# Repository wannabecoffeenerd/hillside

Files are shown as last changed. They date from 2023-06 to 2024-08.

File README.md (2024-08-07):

# Hillside View Ergonomic Keyboard

3x6                       |  3x5
:-------------------------:|:-------------------------:
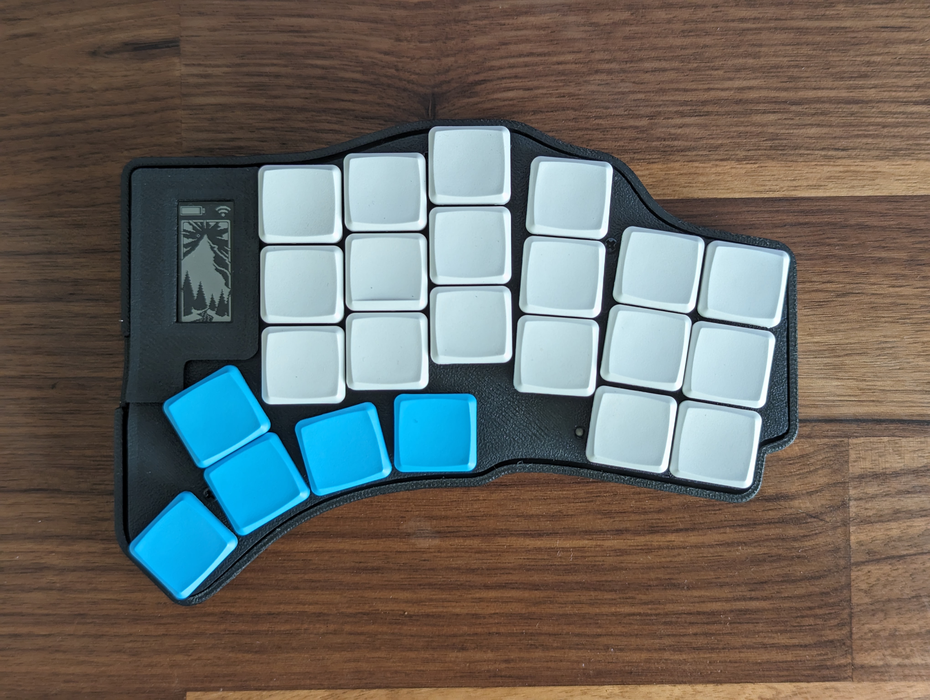
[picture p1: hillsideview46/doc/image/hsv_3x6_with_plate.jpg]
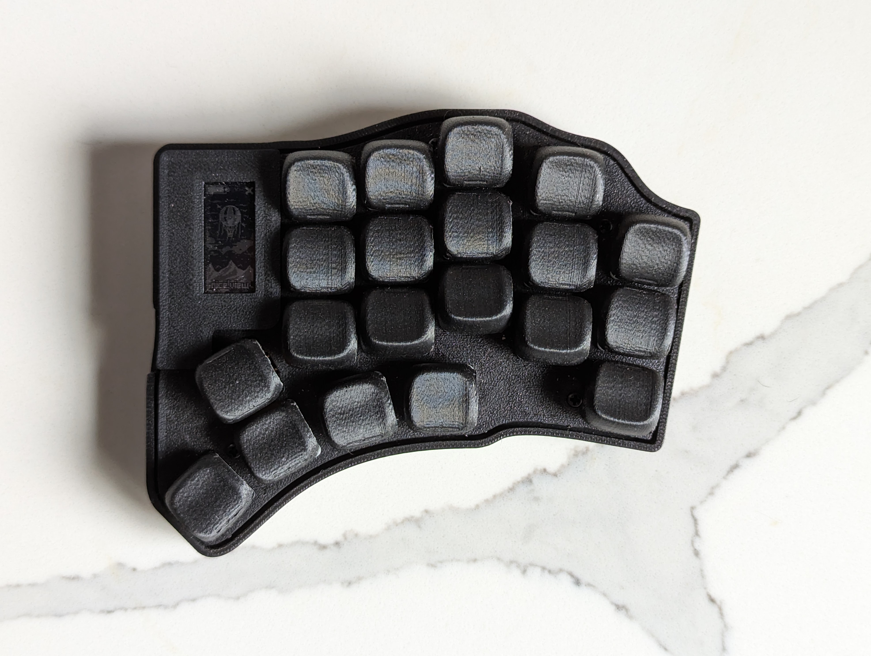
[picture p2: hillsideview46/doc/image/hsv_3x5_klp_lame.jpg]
  |  

The HillSideView (HSV) is a modified version of the [Hillside 46](https://github.com/mmccoyd/hillside). It is a 
 wireless (or wired) [40%](https://deskthority.net/wiki/40%25) 
 split-[ergonomic](https://deskthority.net/wiki/Ergonomic_keyboard) 
 keyboard with a 
 [column-stagger](https://deskthority.net/wiki/Staggering#Columnar_layout) 3x6+5 or a 3x5+5 layout.

The main features that the HSV adds over the Hillside 46 are:
- [nice!view](https://github.com/getkeops/keops/tree/main) e-paper display for better battery life
- Cleaner outer pinky column cut-off
- Support for a cirque trackpad with an FFC connector on the PCB itself
- Case design with support for large 750-3000 mAh batteries under the PCB
- Magnetic tenting stand with the case
- Under PCB mount for the MCU for a cleaner top display mounting

The HSV has optional factory parts soldering (PCBA) except for the switches, MCU, display, TRRS, LEDs, battery switch, and optional hotswap sockets.

Other features of the HSV are:

- Choc-spaced keys, aggressive stagger, five thumb keys
- Break-off outer pinkie column
- Tenting puck support
- QMK and wireless ZMK firmware
- Nice!nano battery power switch
- Encoder support
- Underglow from four or five SK6812-MINI-Es
- Reversible PCB
- Detailed BOM and default keyboard rationale.
- SMT diodes, resistors, capacitors, and reset switch

*Keycaps*: HillSideView is _only_ suitable for choc v1 switches and keycaps based on an 18 x 17mm switch spacing, such as the [MBK](https://mkultra.click/mbk-choc-keycaps), [Lowprokb LDSA](https://lowprokb.ca/products/ldsa-low-profile-blank-keycaps) or [KLP Lamé](https://github.com/braindefender/KLP-Lame-Keycaps/). Not MX ones, nor 18 x 18mm ones such as Work Louder, nor Kailh Choc Transparent.

## Keymap

HillSideView includes ZMK Firmware
- [full size](https://github.com/mike1808/zmk-config)
- [five column](https://github.com/wannabecoffeenerd/zmk-config)

QMK firmware can be adapted from the [Hillside firmware](https://github.com/qmk/qmk_firmware/tree/master/keyboards/handwired/hillside) 

The default keymap for the five column build:


## Key Use

I expect most people will primarily use either the tucked three thumbs or the extended three (not counting the upper thumb). They can choose where the thumb arc suits them best. I find the thumb finger is best for reaching the upper thumb key; clearing the lower thumb requires some care, but it is still very useful. The middle finger also handily reaches the most tucked thumb key, as the open space is a good reference. The keys outside of the primary three thumb keys are convenient for infrequent lock layers, escape, or for use when not actively typing for things such as mute.

## Why

The main reason for this project is to make the keyboard more wireless friendly by adding the e-paper display and allowing experimenting with using a cirque trackpad (once ZMK support for it is more stable)

## Hardware and Build Guide

See the [original Hillside wiki](https://github.com/mmccoyd/hillside/wiki)
 first for PCB ordering, parts links and a build guide with pictures.

See the [HSV wiki](https://github.com/wannabecoffeenerd/HillSideView/wiki) for HSV specific
 build guide.

 ### Bill of Materials (BOM)

| **Component** | **Quantity per keeb** | **URL** | **Source** | **Price Per SKU** |
|---|---|---|---|---|
| PCB | 1 | JLCPCB | JLCPCB | 10.778 |
| nice!nano | 2 | https://typeractive.xyz/products/nice-nano | typeractive.xyz | 25 |
| nice!view | 2 | https://typeractive.xyz/products/nice-view | typeractive.xyz | 20 |
| switches - pro pink or other (10 pack) | 5 | https://lowprokb.ca/collections/keyboards/products/kailh-choc-low-profile-switches | lowprokb.ca | 5 |
| mill-max sockets | 100 | https://www.mouser.com/ProductDetail/Mill-Max/0305-2-15-80-47-80-10-0?qs=QtQX4uD3c2Uys0ai6Tr8NQ%3D%3D | mouser.com | 0.1 |
| keycaps (10 pack) | 5 | https://typeractive.xyz/products/mbk-keycaps | typeractive.xyz | 3.5 |
| 2x battery - 750 mAh | 2 | https://typeractive.xyz/products/lithium-battery-750mah | typeractive.xyz | 6 |
| MCU sockets - low clearance | 2 | https://www.mouser.com/ProductDetail/Mill-Max/310-47-132-41-001000?qs=5aG0NVq1C4z8UdNlP%252Bvotg%3D%3D  | mouser.com | 2.17 |
| Standoffs | 8 | https://www.mouser.com/ProductDetail/Wurth-Elektronik/970060244?qs=%252BEew9%252B0nqrCEb5Os0atlaA%3D%3D | mouser.com | 0.43 |
| MCU pins | 64 | https://www.mouser.com/ProductDetail/Mill-Max/3320-0-00-15-00-00-03-0?qs=s8Nb1z4Wn%2FQ16WBIwCPrTw%3D%3D | mouser.com | 0.05 |
| power switches | 2 | https://www.mouser.com/ProductDetail/CK/JS202011AQN?qs=LgMIjt8LuD%252Bmsz6wAeWWtQ%3D%3D | mouser.com | 0.471 |

Some other optional parts:

| **Component** | **Quantity per keeb** | **URL** | **Source** | **Price Per SKU** |
|---|---|---|---|---|
| battery - 110 mAh | 2 | https://www.aliexpress.us/item/2255800150229489.html | aliexpress.us | 1.36 |
| battery - 2000 mAh | 2 | https://www.aliexpress.us/item/3256803882039204.html | aliexpress.us | 5.18 |
| EC11 rotary encoders | 0.4 | https://www.aliexpress.us/item/2251832789732148.html | aliexpress.us | 5.08 |
| aluminum knob for EC11 | 1 | https://www.aliexpress.us/item/3256801125707035.html | aliexpress.us | 6.85 |

 ### 3DP case

 The HSV is designed to be used with a 3D printed case. STLs for the case are [here](https://github.com/wannabecoffeenerd/HillSideView/tree/main/hillsideview46/case)

 To main design principles for the case are:
 - Ability to use a large battery mounted under the PCB and
 - Keep the top of the HSV fairly low profile for portability and ensure nothing sticks up above the keys.

 This is achieved by having an empty cavity under the PCB that allows using up to a 2000 mAh 306070 battery. This also allows for mounting the MCU on the underside of the PCB and having the nice!view display sit fairly low on top of the PCB.
 
 The case supports tenting using a magnetic tenting stand that uses 10x1 magnets in the case and 10x3 magnets in the stand. This also allows the two sides to attach magnetically for travel.

 

## Acknowledgments

Several keyboards have influenced this boards, primarily the
  [Hillside 46](https://github.com/mmccoyd/hillside), but also
  [Atreus](https://shop.keyboard.io/products/keyboardio-atreus),
  [Lily58](https://github.com/kata0510/Lily58),
  [Kyria](https://splitkb.com/collections/keyboard-kits/products/kyria-pcb-kit),
  [Corne](https://github.com/foostan/crkbd) and
  [Ferris](https://github.com/pierrechevalier83/ferris).

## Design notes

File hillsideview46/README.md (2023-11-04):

# Hillside 46 Ergonomic Keyboard

Hillside46 keyboard

Hillside 46 is a split ergonomic keyboard with 3x6+5 choc-spaced keys.
It has the aggressive stagger of the Ferris plus
  finger splay,
  a longer thumb arc and break-off outer pinkie columns.

Splaying the columns lets our fingers more naturally follows our hand mechanics.
See the Hillside [family readme](../README.md) for features common to all hillside boards. Specific to the Hillside 46 are: 

* Optional factory parts soldering except for the switches, MCU, TRRS, LEDs and battery switch.
* Fab with PCBA is $9 per keyboard for five keyboards, plus shipping.  
  Or $12 each for two keyboards, if the diodes etc are on the left's top side and the right's bottom side.
* Encoder: Two spots for one per side at either: upper or tucked thumb
* Reversible 100 x 143mm PCB
* Optional hotswap with Mill-Max switch sockets (not part of PCBA)

Hillside includes:
 [QMK firmware](https://github.com/qmk/qmk_firmware/tree/master/keyboards/handwired/hillside) 
 with .json, .c, 
 [via](https://github.com/mmccoyd/hillside/wiki/hill_46/via_config.json) and 
 [vial](https://github.com/mmccoyd/vial-qmk/tree/hillside_46/keyboards/handwired/hillside/46/keymaps) keymaps,
 [ZMK Firmware](https://github.com/mmccoyd/zmk-config),
 a [keyboard layout editor](http://www.keyboard-layout-editor.com/) 
 loadable [diagram](https://github.com/mmccoyd/hillside/wiki/hill_46/keyboard-layout-editor.json)
 and a [draw.io](https://app.diagrams.net) 
 loadable [diagram](https://github.com/mmccoyd/hillside/wiki/hill_46/drawio_keymap.png).

## Keymap

The default keymap has a navigation and editing layer and alternate hand modifiers for all keys. See the [keymap descrition](https://github.com/mmccoyd/hillside/wiki/Hillside%2046%20Keymap) for details.

Hillside46 keyboard (https://github.com/mmccoyd/hillside/wiki/Hillside%2046%20Keymap)

## Hardware and Build Guide

See [Ordering Hillside 46](https://github.com/mmccoyd/hillside/wiki/Ordering%20Hillside%2046) 
  for how to order
 and the [wiki](https://github.com/mmccoyd/hillside/wiki)
  generally for parts links and a build guide with pictures.

# Why

The splay is there because your finger tips do not move parallel to each other when you curl and extend them. It makes sense for your keyboard columns to match that.

## Layout Tester
To test if the key layout suits your fingers,
 print these in landscape mode. 
 
  - Click on each to open the GitHub file view in a new tab. 
  - Click on raw to see just the file in the browser tab.
  - Tell your browser to print the file. But ensure it is at 100% and in landscape mode.
  
SVG files contain dimension information, so your browser should print it the correct size regardless of what size paper you are using.
As an extra check, the images each contain marked length lines, which you can check with a ruler.

The images are black lines on whatever the background is, so they do not like browser dark mode backgrounds, but will print black on white.

| switches Switch Layout Left | switches Switch Layout Right |
|---|---|

## Images

<div style="background-color:#DCDCDC;">

Schematic
</div> 

Hillside46 keyboard

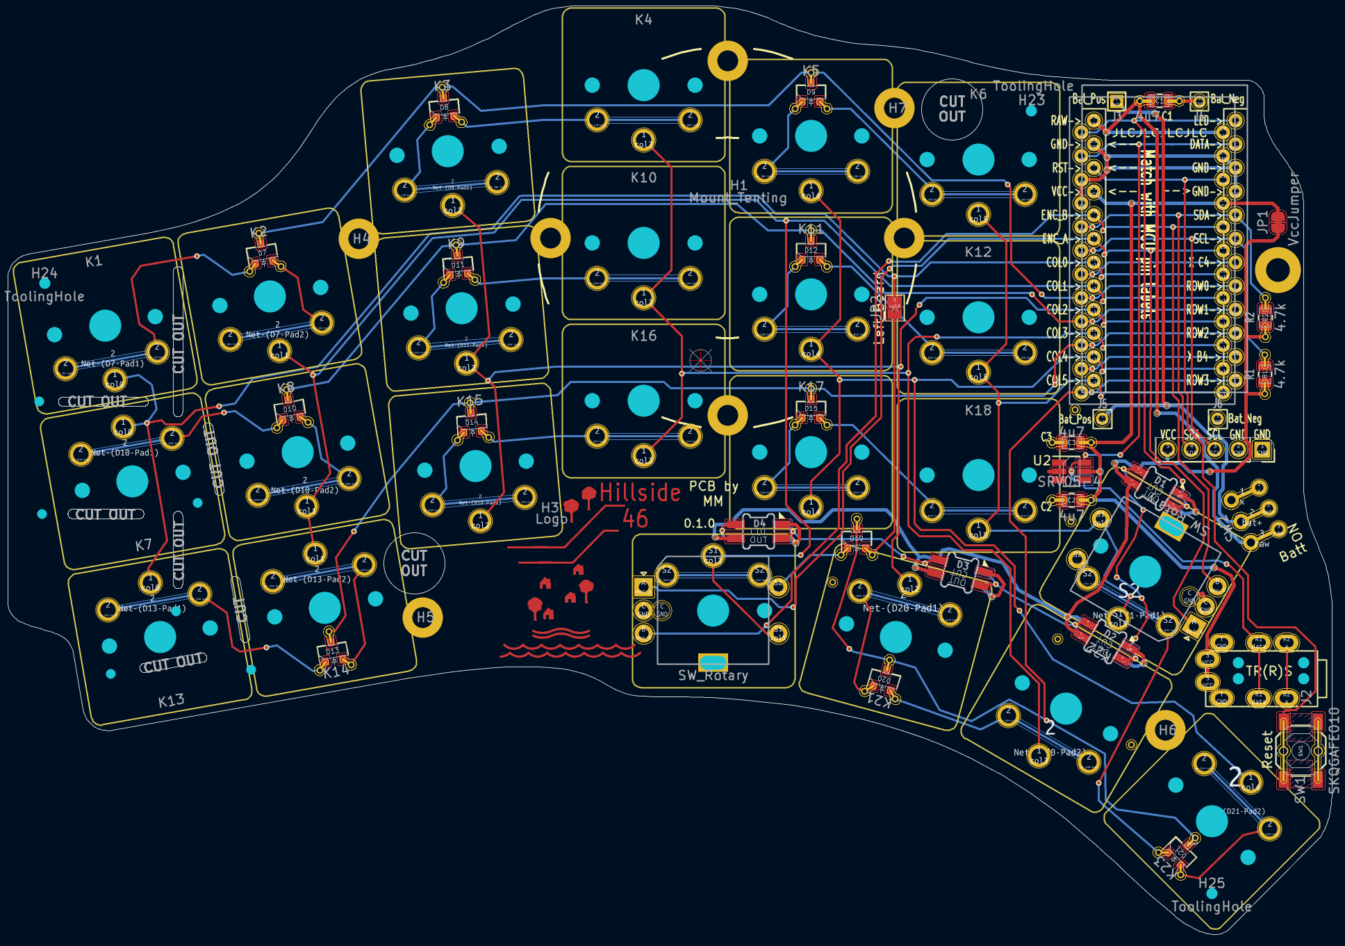
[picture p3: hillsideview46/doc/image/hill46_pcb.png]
pcb PCB


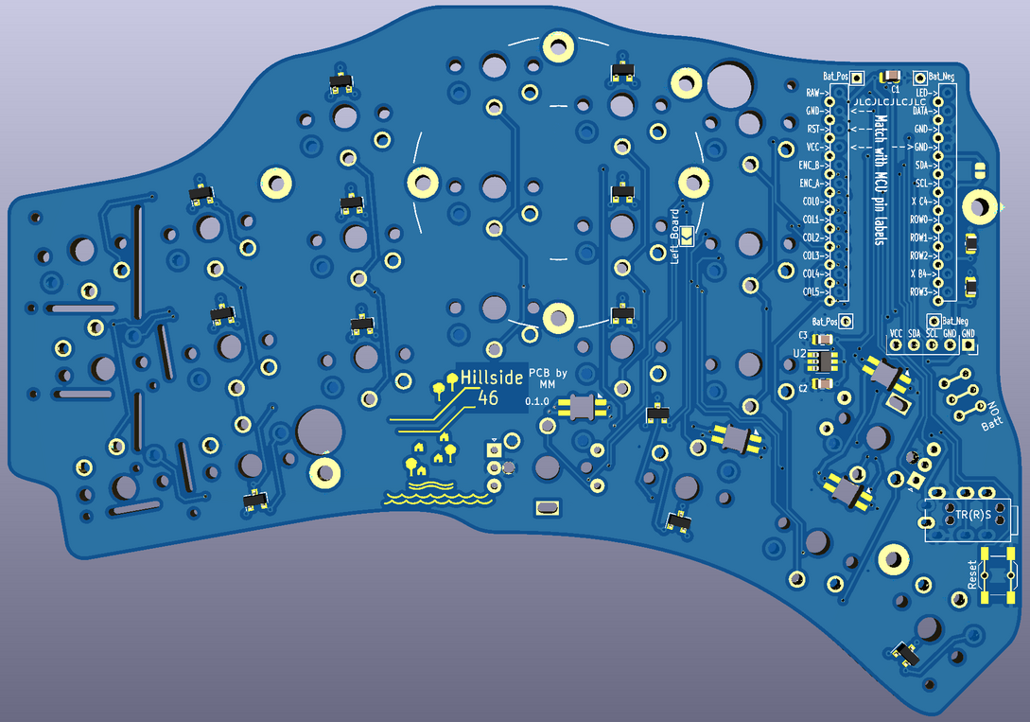
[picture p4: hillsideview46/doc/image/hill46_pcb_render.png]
render Front Render


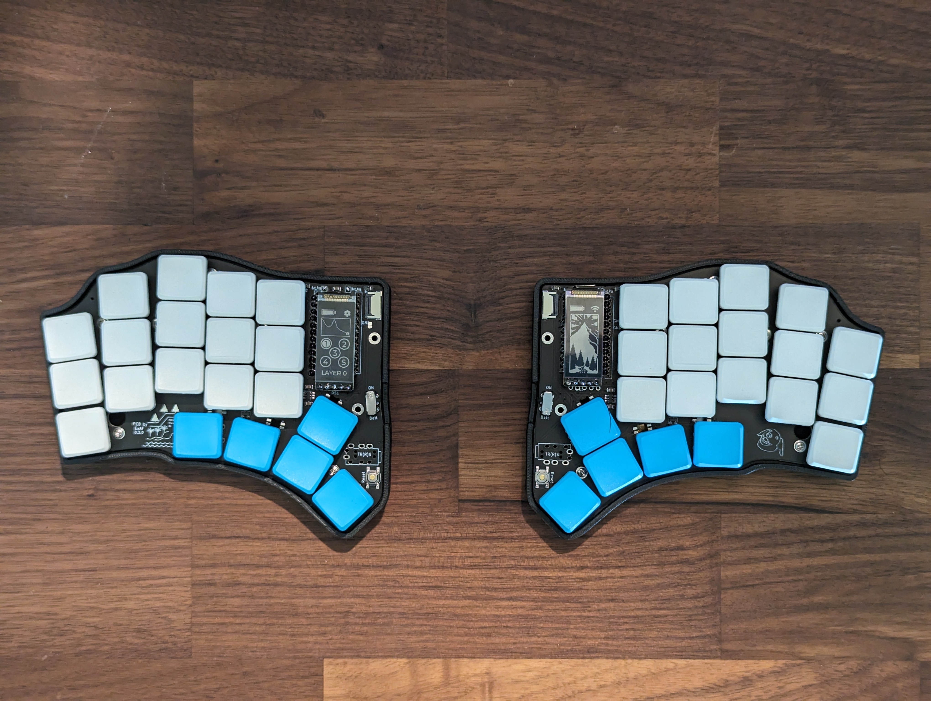
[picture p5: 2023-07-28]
hillsideview46/doc/image/hsv_3x5.jpg

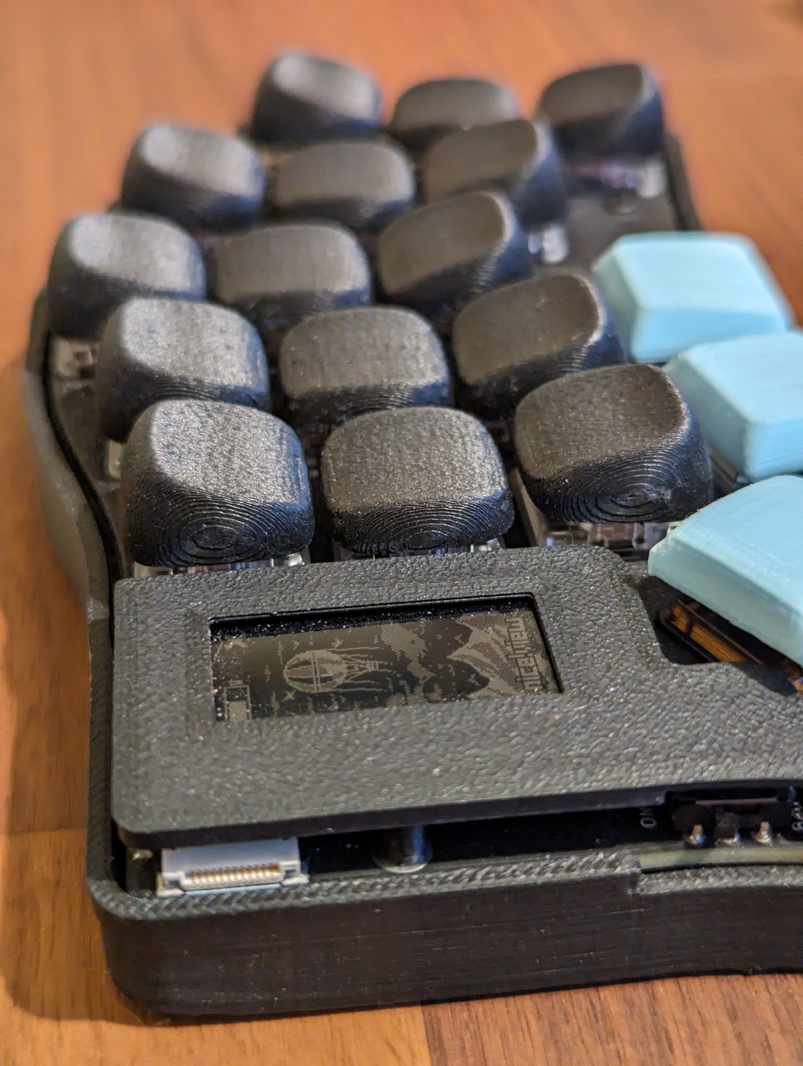
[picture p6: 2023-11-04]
hillsideview46/doc/image/hsv_klp_lame.jpg

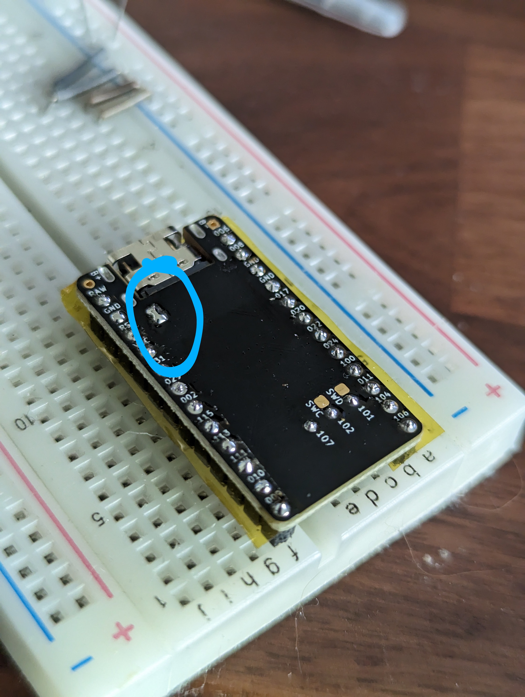
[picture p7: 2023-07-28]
hillsideview46/doc/image/nice_nano_fast_charging.jpg

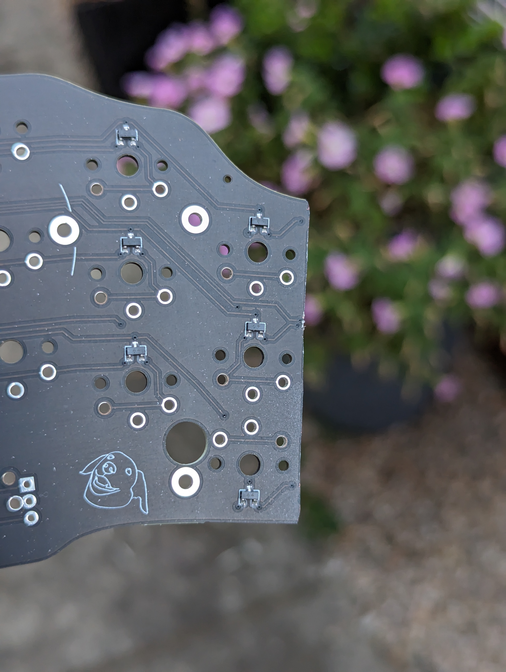
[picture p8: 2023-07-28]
hillsideview46/doc/image/hsv_3x5_pcb.jpg

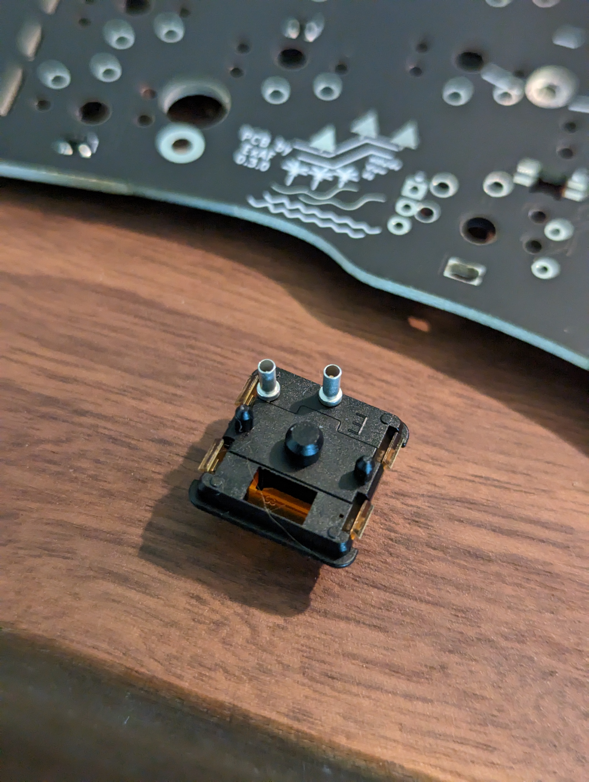
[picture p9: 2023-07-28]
hillsideview46/doc/image/hotswap_on_switch.jpg

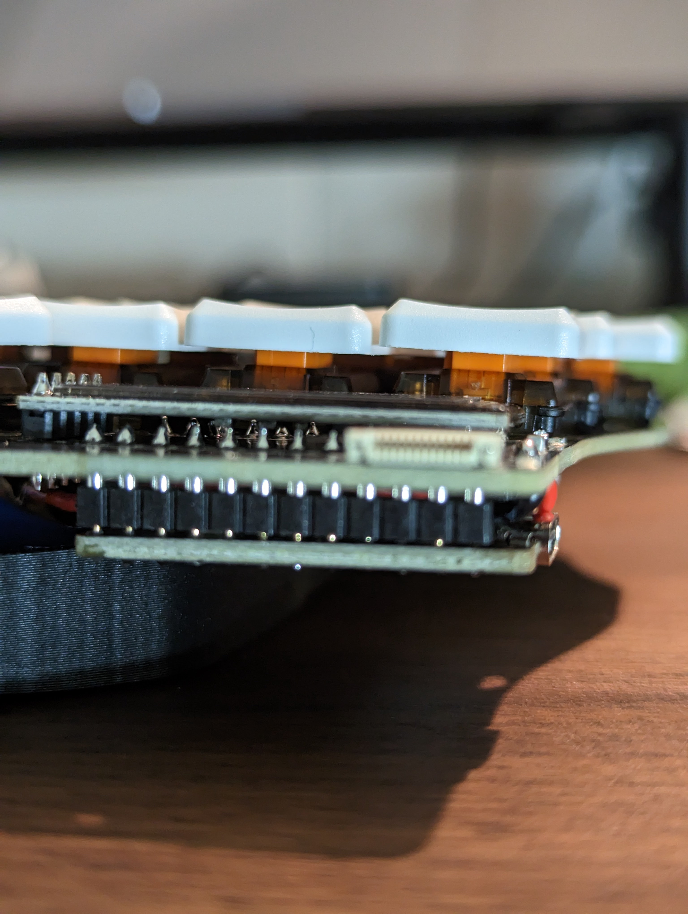
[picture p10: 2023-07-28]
hillsideview46/doc/image/hsv_display_pcb_mcu_side_view.jpg

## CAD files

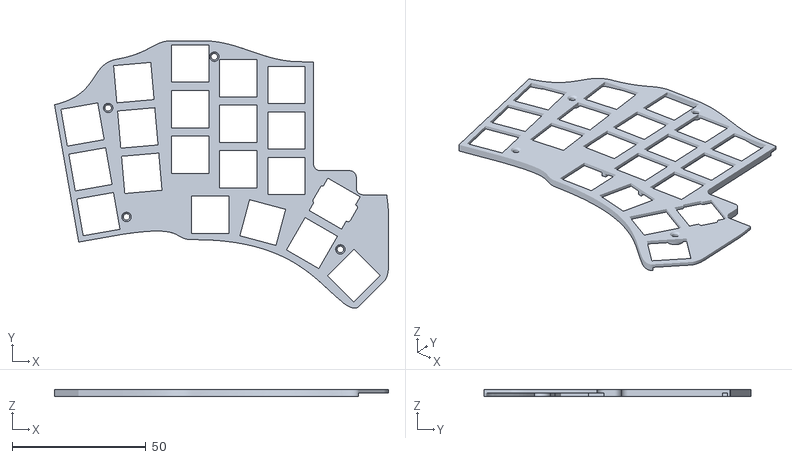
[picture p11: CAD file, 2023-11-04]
hillsideview46/case/5_column/no_pinky_switch_plate.stl
124.8 x 99.9 x 2.50

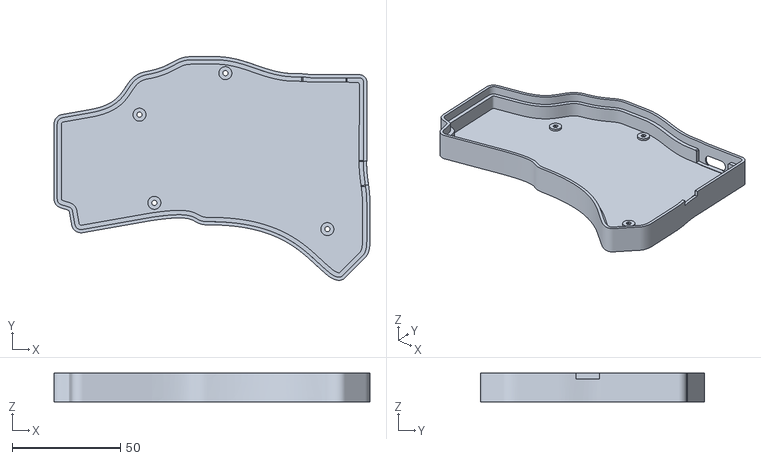
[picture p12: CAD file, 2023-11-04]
hillsideview46/case/6_column/bottom+wall.stl
145.9 x 103.3 x 13.2

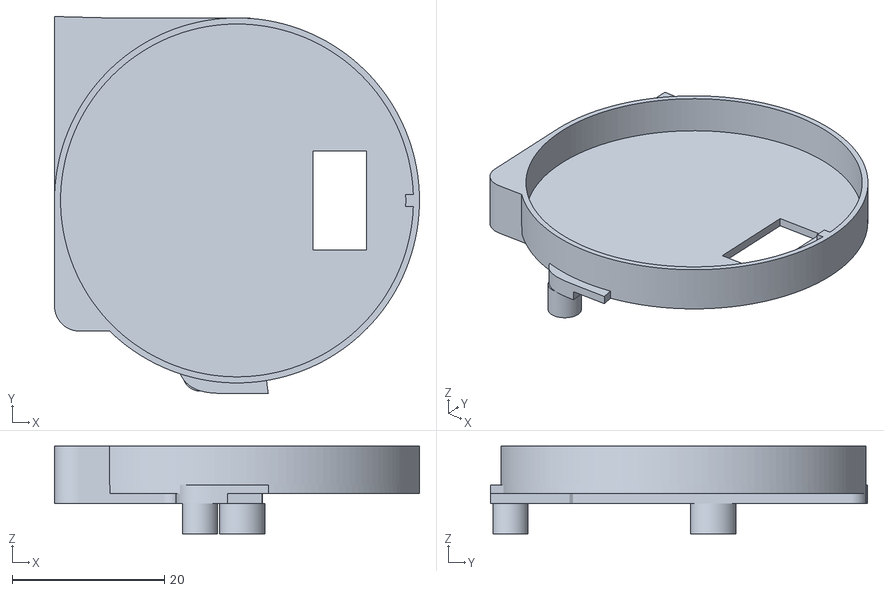
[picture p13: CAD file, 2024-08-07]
hillsideview46/case/cirque/cirque_trackpad_holder.stl
48.0 x 49.6 x 11.6

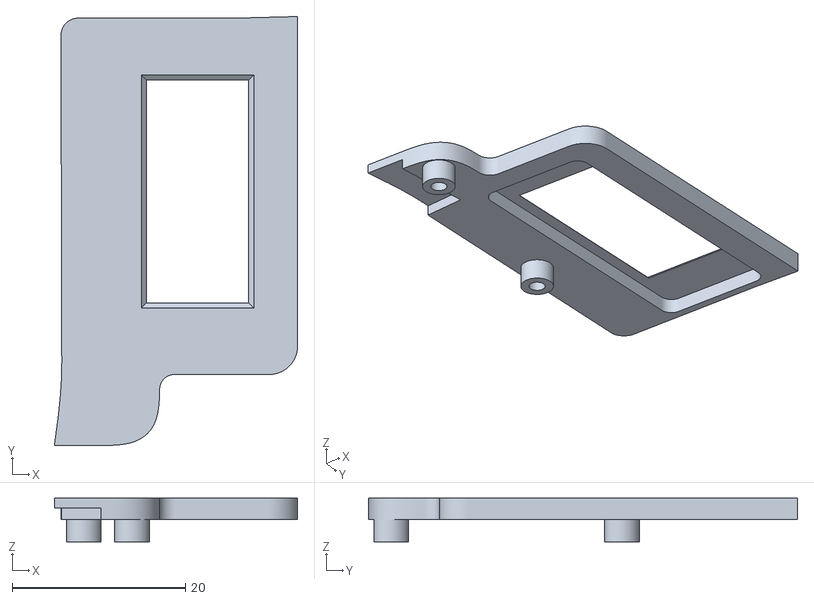
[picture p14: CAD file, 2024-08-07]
hillsideview46/case/display_cover/display_cover_right.stl
28.1 x 49.6 x 5.05

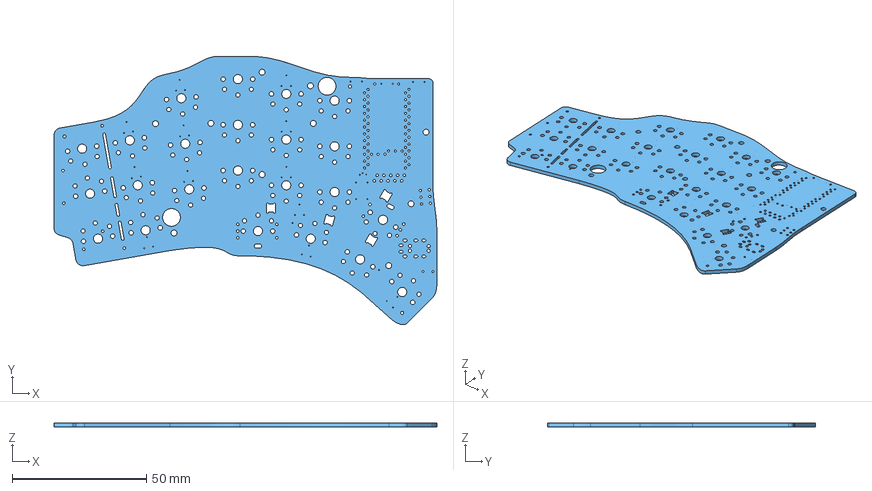
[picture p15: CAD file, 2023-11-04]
hillsideview46/hillsideview46.step
142.5 x 99.9 x 1.60 mm

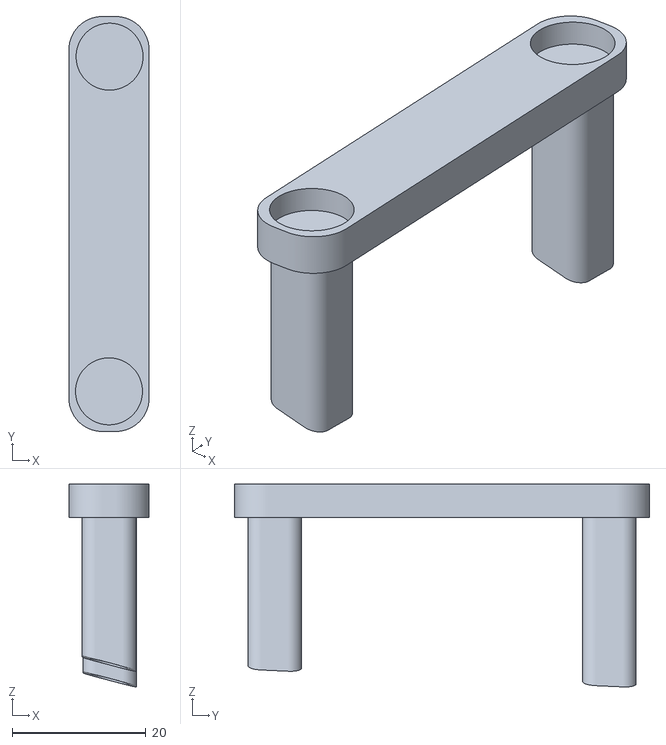
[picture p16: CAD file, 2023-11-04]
hillsideview46/case/5_column/no_pinky_tenting_stand.stl
12.0 x 62.0 x 30.3

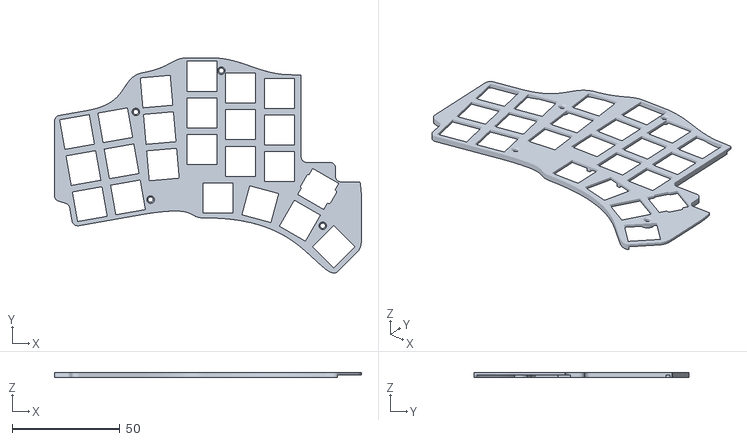
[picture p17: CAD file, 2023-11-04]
hillsideview46/case/6_column/switch_plate.stl
142.5 x 99.9 x 2.50

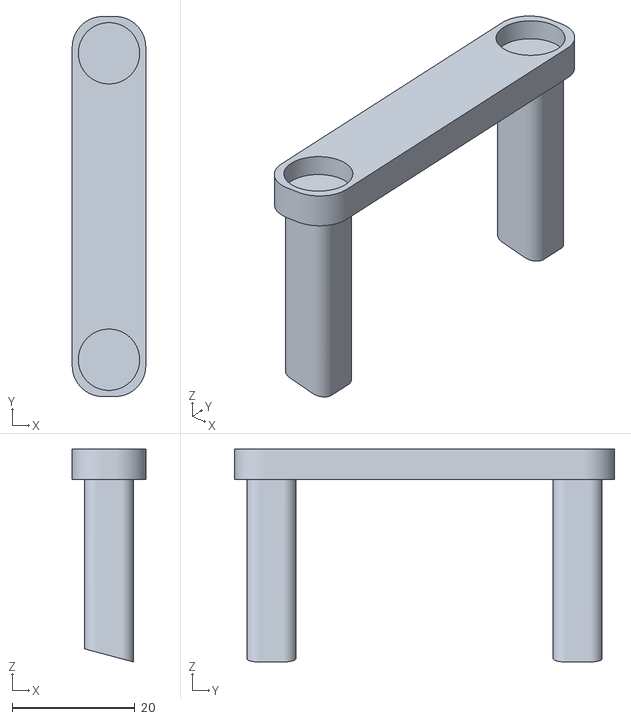
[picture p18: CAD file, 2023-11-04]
hillsideview46/case/6_column/tenting_stand.stl
12.0 x 62.0 x 34.7

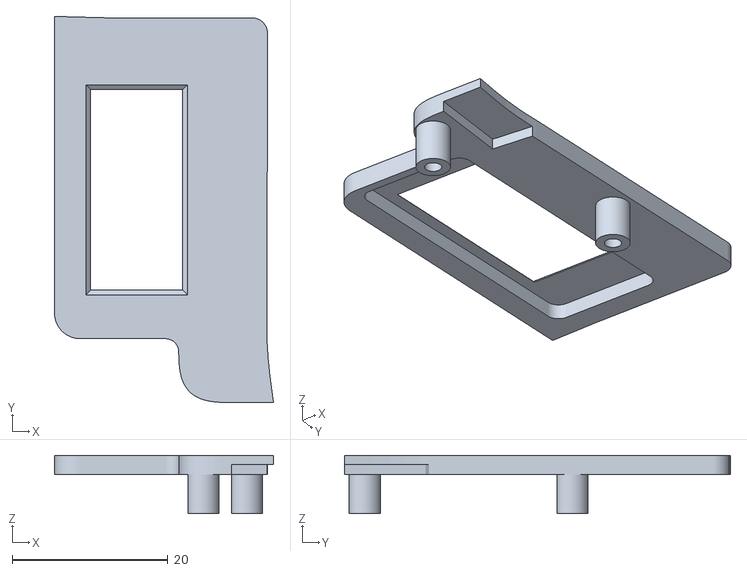
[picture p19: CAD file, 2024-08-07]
hillsideview46/case/display_cover/display_cover_millmax.stl
28.1 x 49.6 x 7.45

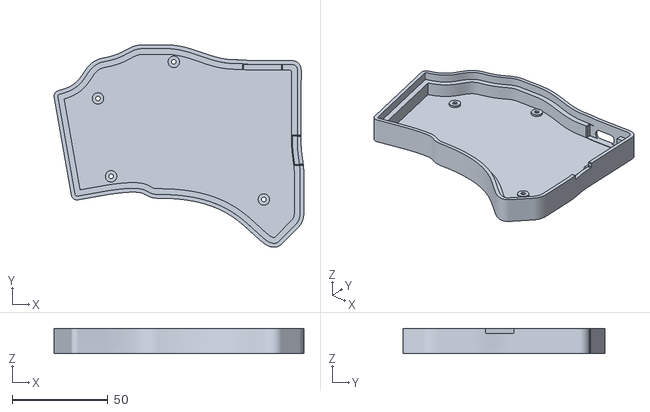
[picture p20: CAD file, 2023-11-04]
hillsideview46/case/5_column/no_pinky_bottom+wall.stl
130.7 x 105.9 x 13.2

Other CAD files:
hillsideview46/case/display_cover/display_cover.stl
hillsideview46/case/5_column/hillside46 - switch_plate.step
hillsideview46/case/display_cover/display_cover_right_millmax.stl
hillsideview46/case/5_column/no_pinky_switch_plate_minimal.stl

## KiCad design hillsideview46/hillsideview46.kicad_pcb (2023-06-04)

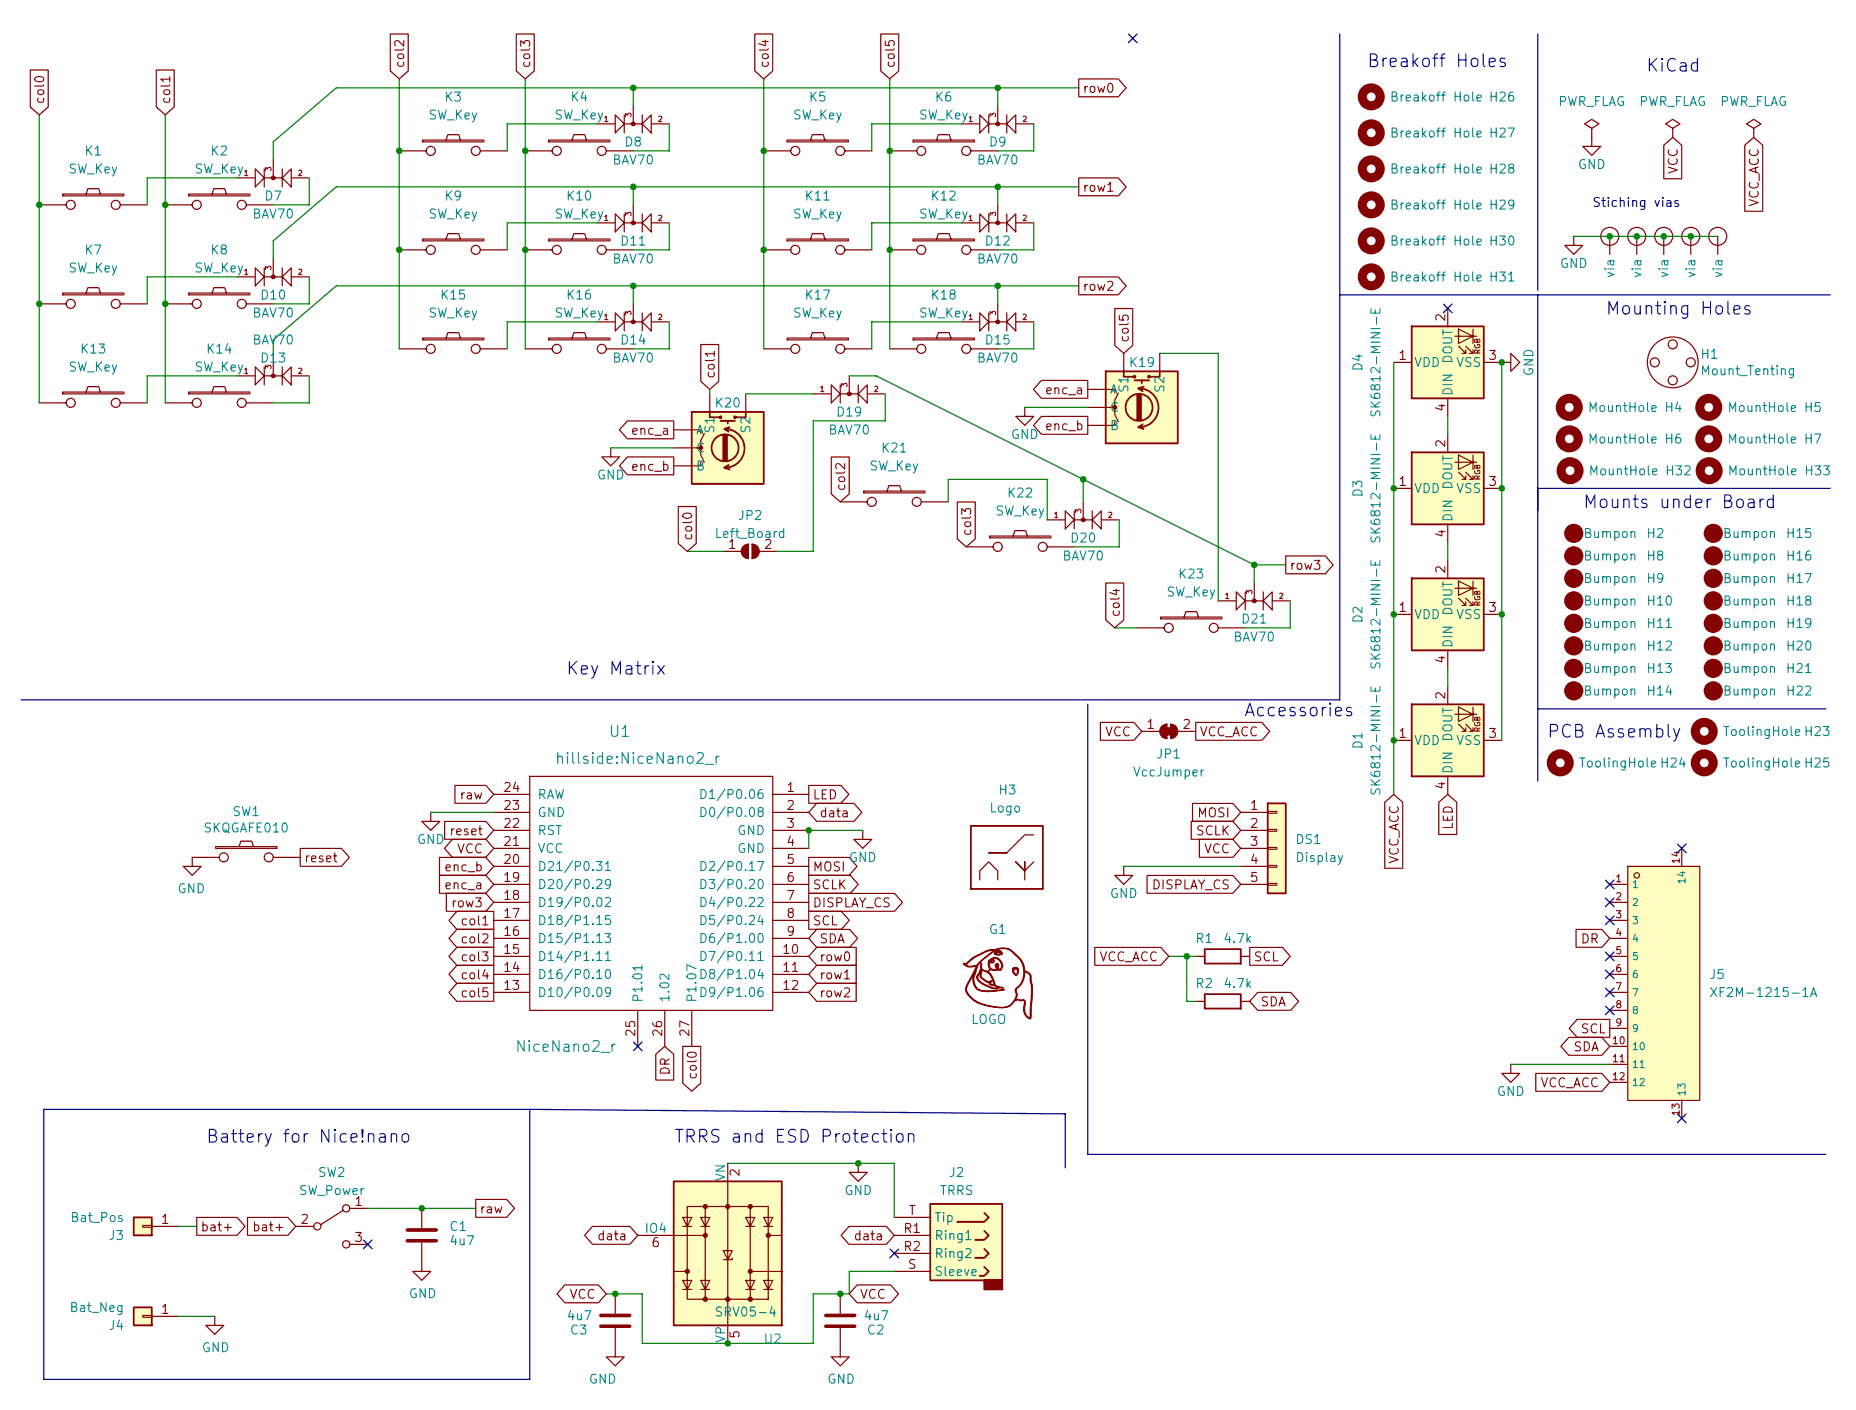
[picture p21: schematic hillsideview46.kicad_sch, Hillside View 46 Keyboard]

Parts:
C1, C2, C3: 4u7; C_0805_2012Metric; JLC Type Basic
D1, D2, D3, D4: SK6812-MINI-E
D7, D8, D9, D10, D11, D12, D13, D14, D15, D19, D20, D21: BAV70; SOT-23; LCSC C68978
DS1: Display; NiceView
G1: LOGO; wowee
H1: Mount_Tenting; Tenting_Puck
H2, H8, H9, H10, H11, H12, H13, H14, H15, H16, H17, H18, H19, H20, H21, H22: Bumpon
H3: Logo; Hillside_Logo
H4, H5, H6, H7, H32, H33: MountHole; MountingHole_2.2mm_with_PCB_insert_rings
H23, H24, H25: ToolingHole; ToolingHole_1.152mm
H26, H27, H28, H29, H30, H31: Breakoff Hole; HoleBreakoff_1mm
J2: TRRS; MJ-4PP-9
J3: Bat_Pos; 1pin_conn
J4: Bat_Neg; 1pin_conn
J5: XF2M-1215-1A; FPC-SMD_12P-P0.50_XF2M-1215-1A; PARTREV A; JLC Type Extended
JP1: VccJumper; SolderJumper-2_P1.3mm_Bridged_RoundedPad1.0x1.5mm
JP2: Left_Board; SolderJumper-2_P1.3mm_Open_TrianglePad1.0x1.5mm
K1, K2, K3, K4, K5, K6, K7, K8, K9, K10, K11, K12, K13, K14, K15, K16, K17, K18, K21, K22, K23: SW_Key; pg1350-R_hotswap
K19, K20: SW_Rotary; pg1350-DR_rotary_hotswap
R1, R2: 4.7k; R_0805_2012Metric; LCSC C17673
SW1: SKQGAFE010; SW_SPST_SKQG_WithStem; LCSC C318884
SW2: SW_Power; SW_SPDT_JS202011AQN; LCSC C221662
U1: NiceNano2_r
U2: SRV05-4; SOT-23-6_Handsoldering_threenumbered; JLC Type Basic
V1, V2, V3, V4, V5: Via; VIA-0.8mm

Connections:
DISPLAY_CS: DS1.5, U1.7 (D4/P0.22)
DR: J5.4, U1.26 (1.02)
GND: C1.2, C2.1, C3.1, D1.3 (VSS), D2.3 (VSS), D3.3 (VSS), D4.3 (VSS), DS1.4, J2.T (Tip), J4.1, J5.11, K19.C, K20.C, SW1.2, U1.3 (GND), U1.4 (GND), U1.23 (GND), U2.2 (VN), V1.1 (via), V2.1 (via), V3.1 (via), V4.1 (via), V5.1 (via)
LED: D1.4 (DIN), U1.1 (D1/P0.06)
MOSI: DS1.1, U1.5 (D2/P0.17)
unnamed: D1.2 (DOUT), D2.4 (DIN)
unnamed: D2.2 (DOUT), D3.4 (DIN)
unnamed: D3.2 (DOUT), D4.4 (DIN)
unnamed: D7.1 (A1), K1.2
unnamed: D7.2 (A2), K2.2
unnamed: D8.1 (A1), K3.2
unnamed: D8.2 (A2), K4.2
unnamed: D9.1 (A1), K5.2
unnamed: D9.2 (A2), K6.2
unnamed: D10.1 (A1), K7.2
unnamed: D10.2 (A2), K8.2
unnamed: D11.1 (A1), K9.2
unnamed: D11.2 (A2), K10.2
unnamed: D12.1 (A1), K11.2
unnamed: D12.2 (A2), K12.2
unnamed: D13.1 (A1), K13.2
unnamed: D13.2 (A2), K14.2
unnamed: D14.1 (A1), K15.2
unnamed: D14.2 (A2), K16.2
unnamed: D15.1 (A1), K17.2
unnamed: D15.2 (A2), K18.2
unnamed: D19.1 (A1), K20.S2
unnamed: D19.2 (A2), JP2.2 (B)
unnamed: D20.1 (A1), K21.2
unnamed: D20.2 (A2), K22.2
unnamed: D21.1 (A1), K19.S2
unnamed: D21.2 (A2), K23.2
SCL: J5.9, R1.2, U1.8 (D5/P0.24)
SCLK: DS1.2, U1.6 (D3/P0.20)
SDA: J5.10, R2.2, U1.9 (D6/P1.00)
VCC: C2.2, C3.2, DS1.3, J2.S (Sleeve), JP1.1 (A), U1.21 (VCC), U2.5 (VP)
VCC_ACC: D1.1 (VDD), D2.1 (VDD), D3.1 (VDD), D4.1 (VDD), J5.12, JP1.2 (B), R1.1, R2.1
bat+: J3.1, SW2.2 (B)
col0: JP2.1 (A), K1.1, K7.1, K13.1, U1.27 (P1.07)
col1: K2.1, K8.1, K14.1, K20.S1, U1.17 (D18/P1.15)
col2: K3.1, K9.1, K15.1, K21.1, U1.16 (D15/P1.13)
col3: K4.1, K10.1, K16.1, K22.1, U1.15 (D14/P1.11)
col4: K5.1, K11.1, K17.1, K23.1, U1.14 (D16/P0.10)
col5: K6.1, K12.1, K18.1, K19.S1, U1.13 (D10/P0.09)
data: J2.R1 (Ring1), U1.2 (D0/P0.08), U2.6 (IO4)
enc_a: K19.A, K20.A, U1.19 (D20/P0.29)
enc_b: K19.B, K20.B, U1.20 (D21/P0.31)
raw: C1.1, SW2.1 (A), U1.24 (RAW)
reset: SW1.1, U1.22 (RST)
row0: D7.3 (K), D8.3 (K), D9.3 (K), U1.10 (D7/P0.11)
row1: D10.3 (K), D11.3 (K), D12.3 (K), U1.11 (D8/P1.04)
row2: D13.3 (K), D14.3 (K), D15.3 (K), U1.12 (D9/P1.06)
row3: D19.3 (K), D20.3 (K), D21.3 (K), U1.18 (D19/P0.02)

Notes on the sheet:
KiCad
Mounting Holes
Key Matrix
Battery for Nice!nano
TRRS and ESD Protection
PCB Assembly
Stiching vias
Breakoff Holes
Mounts under Board
Accessories

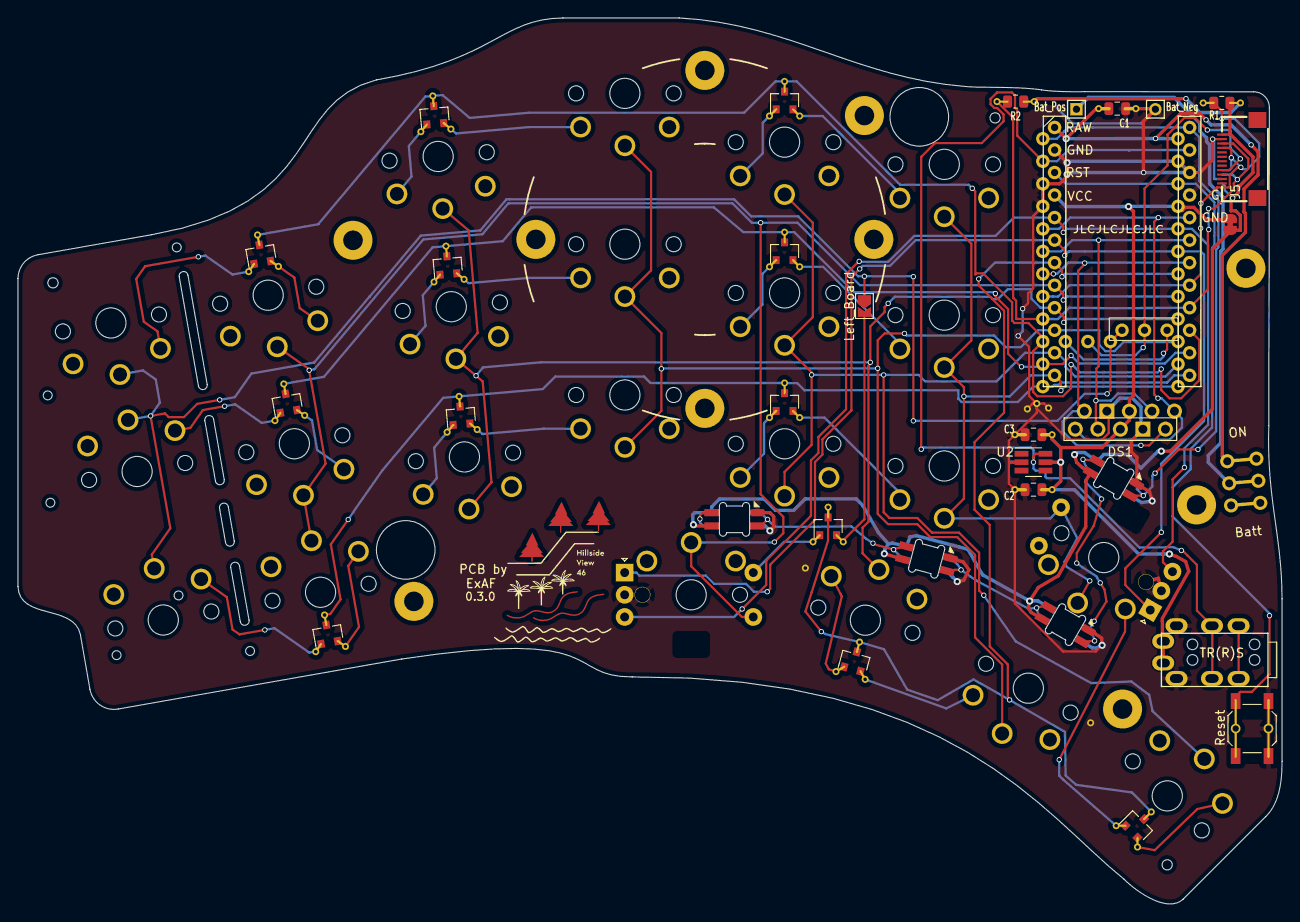
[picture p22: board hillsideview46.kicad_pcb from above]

Board: 2 copper layers, 142.5 x 99.9 mm, 94 parts (1 on the bottom side), 53 nets.

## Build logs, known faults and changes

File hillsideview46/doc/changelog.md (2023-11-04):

# Version 0.1.0

The initial Hillside 46 release.

Key differences from the Hillside 48:

- 46 keys, removing the extra key under the ring column.
- Splay of five and ten degrees for the ring and pinkie columns.
- PCBA for diodes and other SMT, except LEDs
- Two spots for one encoder per side.
- Hotswap switch option using Mill-Max sockets.

Key differences from the Hillside 52:

- No bottom utility/arrow row
- PCBA

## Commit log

2022-10-10 Adding nice view footprints and removing old haptic buzzer, I2C pullup resistors and all LEDs
    [hillside46.kicad_pcb, hillside46.kicad_sch]
2022-10-17 Adding cirque connector to the under side of the PCB for right side assembly
    [hillside46.kicad_pcb]
2022-10-17 Adding some JLCPCB part numbers
    [hillside46.kicad_sch]
2022-10-17 Updating ffc footprint to not require unused pads to be connected
    [hillside46.kicad_pcb]
2022-10-18 Denoting ffc connector as SMD for PCBA
    [hillside46.kicad_pcb]
2022-10-19 Updating FFC connector to use the same footprint as JLCPCB part and rotating by 180 degrees to orient correctly
    [hillside46.kicad_pcb, hillside46.kicad_sch]
2022-10-19 Updating pcb art
    [hillside46.kicad_pcb, hillside46.kicad_sch]
2022-12-18 Move switch, flip the copper on DS
    Move the switch to the side of the PCB to make it easier to swtich.
    Flip the copper layer for the display connector.
    [hillside46.kicad_pcb, hillside46.kicad_sch]
2023-01-30 Connecting the data ready pin
    [hillside46.kicad_pcb, hillside46.kicad_sch]
2023-05-15 Flipping nice nano vias for bottom mount, removed I2C headers, moved edge cut closer to the nice nano edge
    [hillside46.kicad_pcb, hillside46.kicad_sch]
2023-05-22 Updating pinky column cutouts to be aligned with pinky switches
    [hillside46.kicad_pcb]
2023-06-04 Adding mounting holes for the display cover
    [hillside46.kicad_pcb, hillside46.kicad_sch]
2023-06-04 Fixing warning with overlapping silk screen text
    [hillside46.kicad_pcb]
2023-11-04 Adding case STLs
    [bottom+wall.stl, display_cover.stl, display_cover_millmax.stl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]
2023-11-04 Cleaning up repo
    [bottom+wall.stl, display_cover.stl, display_cover_millmax.stl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]
2023-11-04 Updating README.md to include case link and fixing images
2023-11-04 Renaming kicad project to hillsideview46
    [hillsideview46-CuBottom.gbr, hillsideview46-CuTop.gbr, hillsideview46-EdgeCuts.gbr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]
2023-11-05 More documentation and adding BOM
2024-08-07 Updating case STLs and adding cirque trackpad holder
    [cirque_trackpad_holder.stl, display_cover.stl, display_cover_millmax.stl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]
